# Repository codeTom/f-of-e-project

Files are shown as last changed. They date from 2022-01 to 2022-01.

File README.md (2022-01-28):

# Time of flight sensor based 3D mapper
## About
This project builds a slow 3D lidar alternative using 2 servos and a time of flight sensor.

## Firmware
The firmware is based on a stripped down version of [Warp-firmware](https://github.com/physical-computation/Warp-firmware), source can be found in src.
### Servo control
Servo driver can control 2 servos, see `src/boot/ksdk1.1.0/devServos.{h,c}` for more details. To allow higher resolution for PWM control, the default PWM driver was modified and now uses 1/1000 percent instead of percent for duty cycle unit.

### Distance sensor
A basic VL53L0X V2 driver is implemented in `src/boot/ksdk1.1.0/devVL53.{c,h}` based on [this post](https://www.artfulbytes.com/vl53l0x-post).

### Communication
The firmware sends data using the default warpPrint() function and it can be read using the standard JLink connection.

## Hardware
Models directory contains the 3D printed attachments (source in `servoholder.scad`) and the box svg file for 3mm material thickness. The openscad file requires some external stls for servos and the sensor which were obtained from grabcad.com. Servo arm scad file is from [this repo](https://github.com/hugokernel/OpenSCAD_ServoArms).

## Software and processing
`python/live.py` will display live data as they arrive and also output it to terminal for future processing. Make sure the JLink server is running and connected while using the script. As the live display in matplotlib is very slow, it's recommended to log output from live.py to a file and use `python/postprocess.py` to display it after a full scan was completed.

## How to reproduce this project
### Materials list
 * FRDM board
 * 2 9g Servos
 * VL53L0X V2 sensor
 * Some wires, optionally a breadboard
 * 3D printer
 * (optional) Laser cutter and 3mm material
 * 2 M3 screws
 * 4 M2 screws
 * 2 M2 nuts

### Process
1. Print `servoholder.stl` and `sensorholder.stl`.
2. Attach distance sensor to sensorholder
3. Screw servo to servoholder
4. Glue the larger servohorn to servoholder (elevation servo)
5. Connect the distance sensor to i2c on the FRDM
6. Load firmware to FRDM (`make warp && make warp-load`)
7. Attach small servo horn to the servo in the holder
8. Connect servo in the holder to 5V, ground and PTB11 (temporary)
9. Observe servo motion and adjust rotation of the arm so that it goes from horizontal to horizontal
10. Power off FRDM
11. Screw the sensor holder to the servo arm (securing the arm to the servo)
12. (optional) Cut and assemble the box, screw azimuth servo to the box and place FRDM in the box
13. Attach the servo holder to the azimuth servo so that the axes of the servo intersect (to reduce errors slightly)
14. Move elevation servo data cable to PTB10 (routing the cable sensibly)
15. Connect elevation servo to 5V, ground, and PTB11
16. Plug FRDM back in
17. Connect ot FRDM with JLink
18. Start `python/live.py > data.csv` and see the scan progress

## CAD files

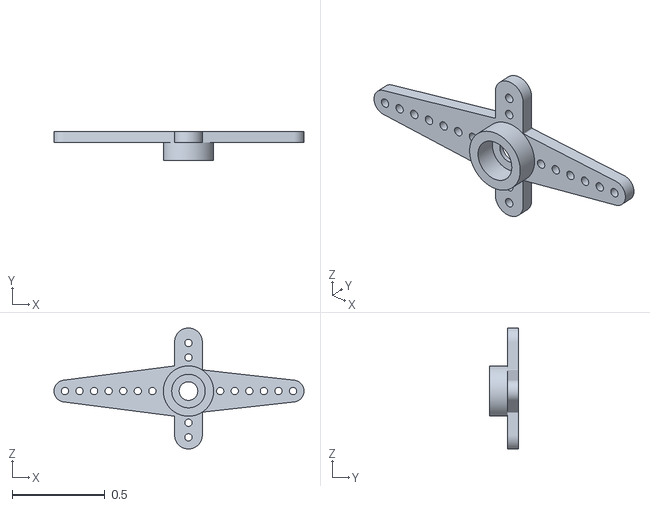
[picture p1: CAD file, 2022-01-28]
models/largearm.stl
1.35 x 0.157 x 0.654

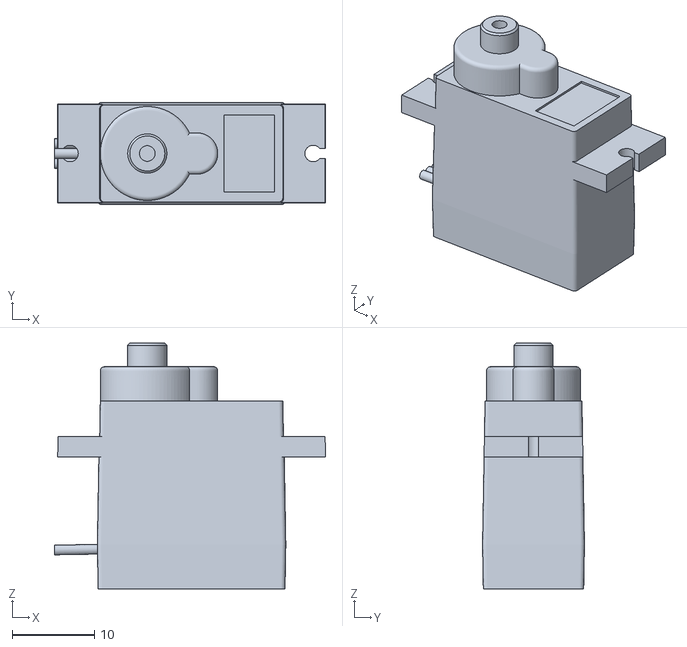
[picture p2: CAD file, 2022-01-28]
models/servo.stl
32.9 x 12.4 x 29.8

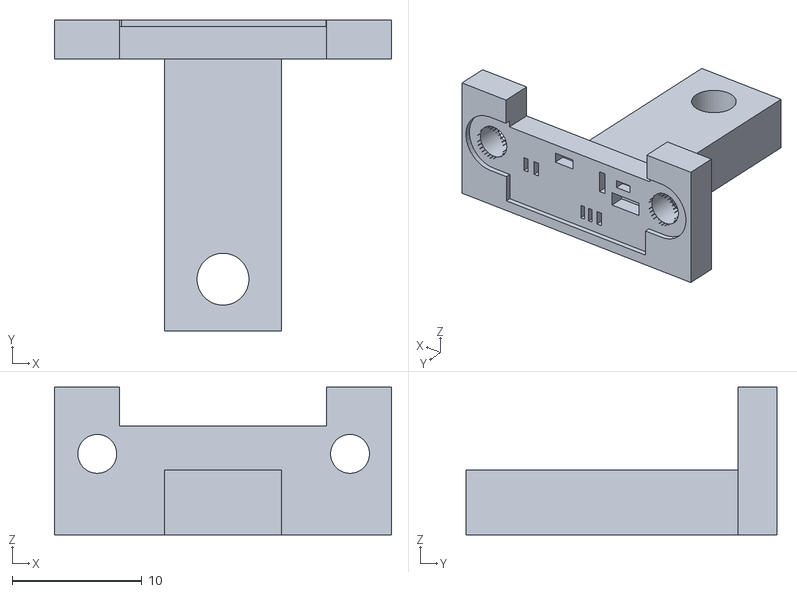
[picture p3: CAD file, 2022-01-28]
models/sensorholder.stl
26.0 x 24.0 x 11.4

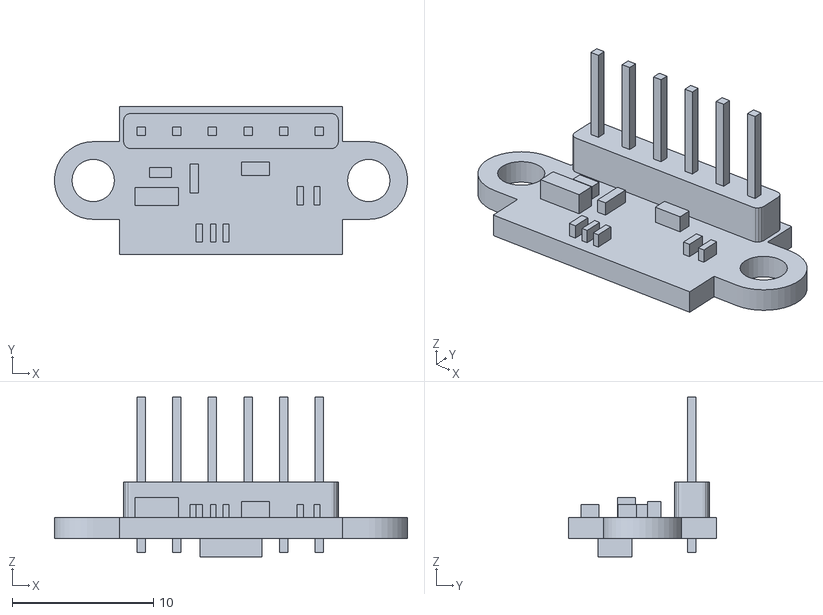
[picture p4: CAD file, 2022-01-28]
models/sensor.stl
25.0 x 10.5 x 11.3

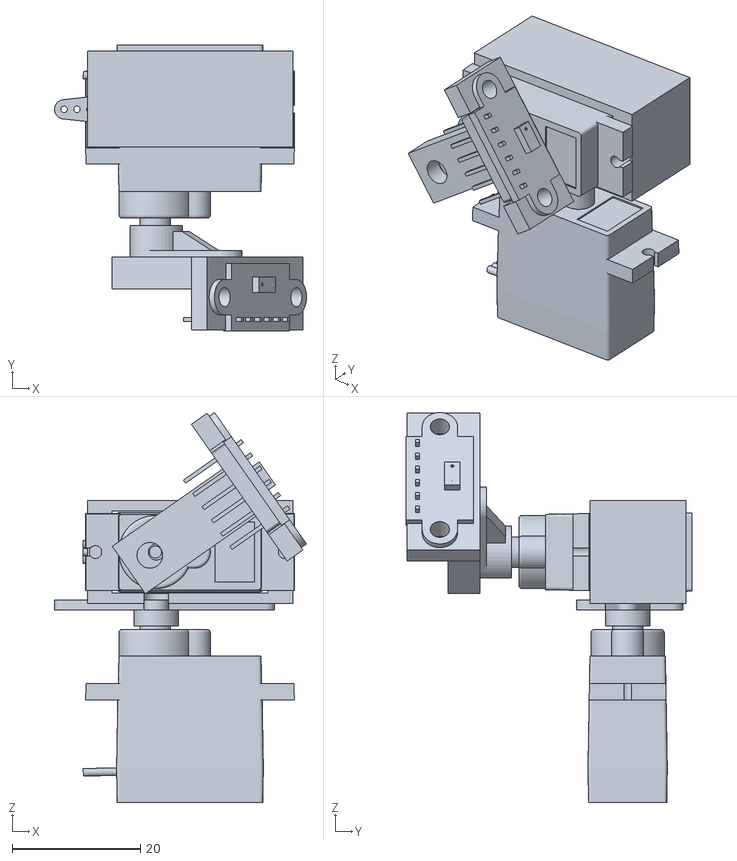
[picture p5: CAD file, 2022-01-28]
models/figure.stl
39.2 x 44.5 x 60.7

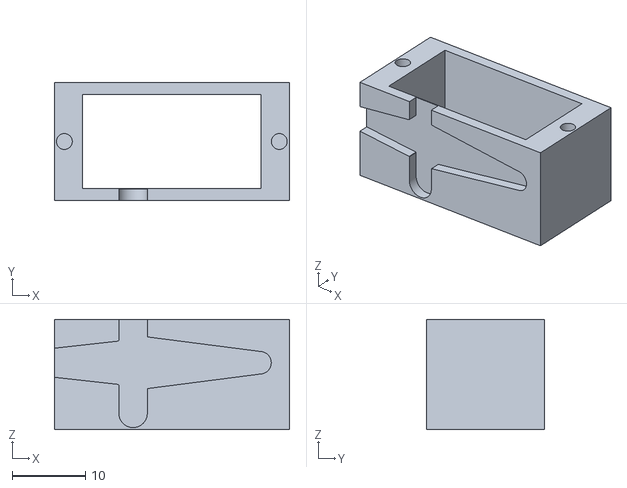
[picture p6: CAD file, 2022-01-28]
models/servoholder.stl
32.0 x 16.0 x 15.0

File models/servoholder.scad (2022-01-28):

use <MCAD/servos.scad>
use <servo_arm.scad>

$fn=50;

SERVO = [
    [5, 4, 1, 1.5],
    [25, 0.3, 0.7, 0.1]
];

module parts()
{
    hull()servo_arm(SERVO, [14,1]);
    translate([-19.7,21,-5])
    rotate([90,0,0])
        color("green")import("sensor.stl");
}

module screwholes()
{
    translate([0,0,2])cylinder(r=2,h=12,$fn=50);
    translate([-9.7,22,10.25])rotate([90,0,0]) cylinder(r=1.5, h=7, $fn=50);
    translate([9.8,22,10.25])rotate([90,0,0]) cylinder(r=1.5, h=7, $fn=50);
}

module core()
{
    plate_thickness = 3;
    translate([-4.5,-4,4])cube([9,24,5]);
    translate([-13,20-plate_thickness,4]) cube([26,plate_thickness,8.4]);
    translate([-13,20-plate_thickness,4+8.4]) cube([5,plate_thickness,3]);
    translate([8,20-plate_thickness,4+8.4]) cube([5,plate_thickness,3]);
}

/**
 * taken from https://github.com/openscad/MCAD/blob/master/servos.scad 
 *
 * @param vector position The position vector
 * @param vector rotation The rotation vector
 * @param boolean screws If defined then "screws" will be added and when the module is differenced() from something if will have holes for the screws
 * @param boolean cables If defined then "cables" output will be added and when the module is differenced() from something if will have holes for the cables output
 * @param number axle_length If defined this will draw a red indicator for the main axle
 */
module towerprosg90(position=undef, rotation=undef, screws = 0, axle_length = 0, cables=0)
{
	translate(position) rotate(rotation) {
        difference(){
            union()
            {
                translate([-5.9,-11.8/2,0]) cube([22.5,11.8,22.7]);
                translate([0,0,22.7-0.1]){
                    cylinder(d=11.8,h=4+0.1);
                    hull(){
                        translate([8.8-5/2,0,0]) cylinder(d=5,h=4+0.1);
                        cylinder(d=5,h=4+0.1);
                    }
                    translate([0,0,4]) cylinder(d=4.6,h=3.2);
                }
                translate([-4.7-5.9,-11.8/2,15.9]) cube([22.5+4.7*2, 11.8, 2.5]); 
            }
            //screw holes
            translate([-2.3-5.9,0,15.9+1.25]) cylinder(d=2,h=5, center=true);
            translate([-2.3-5.9-2,0,15.9+1.25]) cube([3,1.3,5], center=true);
            translate([2.3+22.5-5.9,0,15.9+1.25]) cylinder(d=2,h=5, center=true);
            translate([2.3+22.5-5.9+2,0,15.9+1.25]) cube([3,1.3,5], center=true);
        }
        if (axle_length > 0) {
            color("red", 0.3) translate([0,0,29.9/2]) cylinder(r=1, h=29.9+axle_length, center=true);
        }
        if (cables > 0) color("red", 0.3) translate([-12.4,-1.8,4.5]) cube([10,3.6,1.2]);
        if(screws > 0) color("red", 0.3) {
            translate([-2.3-5.9,0,15.9+1.25]) cylinder(d=2,h=10, center=true);
            translate([2.3+22.5-5.9,0,15.9+1.25]) cylinder(d=2,h=10, center=true);
        }
    }
    
}

module sensorholder()
{
    difference()
    {
        core();
        parts();
        screwholes();
    }
}


module largearm()
{
    intersection()
    {
        translate([-25,-0.1,-25])cube([50,50,50]);
        scale([25.4,25.4,25.4]) rotate([0,180,0])import("largearm.stl"); //stl from grabcad
    }

    translate([1.1,0.75,0])cube([33,1.5,2], center=true);
    translate([0,0.75,0]) cube([2,1.5,15], center=true);
    translate([0,0.75,0])rotate([90,0,0]) cylinder(h=1.5, r=2.8, center=true);
}

module servoholder()
{
    difference()
    {
        translate([-10.7,-8,0.9])cube([32,16,15]);
        translate([-0.5,0,0])scale([1.08,1.08,1])towerprosg90([0,0,0], [0,0,0], 1, 0, 0);
        translate([0,-8,10]) scale([1.02,1.02,1.02]) largearm();
    }
}

servoholder();

//towerprosg90([0,0,0], [0,0,0], 1, 0, 0);

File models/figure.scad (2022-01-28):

use <servoholder.scad>;
use <servo_arm.scad>

SERVO = [
    [5, 4, 1, 1.5],
    [25, 0.3, 0.7, 0.1]
];

module servo()
{
    translate([0,-51,0])color("lightblue") import("servo.stl");
}

module sensor()
{
    color("green")import("sensor.stl");
}
servo();
translate([10,10,23])rotate([90,0,0])
{
    color("white")translate([0,-9,10])scale([25.4,25.4,25.4]) rotate([0,180,0])import("largearm.stl");
    servoholder();
}
translate([0,-6,23]) rotate([90,0,0]) servo();
color("white")translate([10,-18,23])rotate([90,55,0])servo_standard(13, 1);
//translate([35,-10,0])rotate([-25,0,-90])rotate([0,90,0])sensor();

translate([9,-19,22.5])rotate([90,55,0]){
    sensorholder();
translate([-19.7,21,-5])
    rotate([90,0,0])
        color("green")import("sensor.stl");
}

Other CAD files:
models/servo_arm.scad

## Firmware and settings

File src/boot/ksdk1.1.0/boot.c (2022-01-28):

/*
	Authored 2016-2018. Phillip Stanley-Marbell.

	Additional contributions, 2018 onwards: See git blame.

	All rights reserved.

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
	*	Neither the name of the author nor the names of its
		contributors may be used to endorse or promote products
		derived from this software without specific prior written
		permission.

	THIS SOFTWARE IS PROVIDED BY THE COPYRIGHT HOLDERS AND CONTRIBUTORS
	"AS IS" AND ANY EXPRESS OR IMPLIED WARRANTIES, INCLUDING, BUT NOT
	LIMITED TO, THE IMPLIED WARRANTIES OF MERCHANTABILITY AND FITNESS
	FOR A PARTICULAR PURPOSE ARE DISCLAIMED. IN NO EVENT SHALL THE
	COPYRIGHT OWNER OR CONTRIBUTORS BE LIABLE FOR ANY DIRECT, INDIRECT,
	INCIDENTAL, SPECIAL, EXEMPLARY, OR CONSEQUENTIAL DAMAGES (INCLUDING,
	BUT NOT LIMITED TO, PROCUREMENT OF SUBSTITUTE GOODS OR SERVICES;
	LOSS OF USE, DATA, OR PROFITS; OR BUSINESS INTERRUPTION) HOWEVER
	CAUSED AND ON ANY THEORY OF LIABILITY, WHETHER IN CONTRACT, STRICT
	LIABILITY, OR TORT (INCLUDING NEGLIGENCE OR OTHERWISE) ARISING IN
	ANY WAY OUT OF THE USE OF THIS SOFTWARE, EVEN IF ADVISED OF THE
	POSSIBILITY OF SUCH DAMAGE.
*/
#include <stdio.h>
#include <stdlib.h>
#include <string.h>
#include <stdarg.h>

/*
 *	config.h needs to come first
 */
#include "config.h"

#include "fsl_misc_utilities.h"
#include "fsl_device_registers.h"
#include "fsl_i2c_master_driver.h"
#include "fsl_spi_master_driver.h"
#include "fsl_rtc_driver.h"
#include "fsl_clock_manager.h"
#include "fsl_power_manager.h"
#include "fsl_mcglite_hal.h"
#include "fsl_port_hal.h"
#include "fsl_lpuart_driver.h"
#include "warp.h"
#include "errstrs.h"
#include "gpio_pins.h"
#include "SEGGER_RTT.h"
#include "devINA219.h"
//#include "fsl_tpm_hal.h"
#include "fsl_tpm_driver.h"
#include "devServos.h"
#include "devVL53.h"

#define kWarpConstantStringI2cFailure "\rI2C failed, reg 0x%02x, code %d\n"
#define kWarpConstantStringErrorInvalidVoltage "\rInvalid supply voltage [%d] mV!"
#define kWarpConstantStringErrorSanity "\rSanity check failed!"

#if (WARP_BUILD_ENABLE_DEVSSD1331)
#include "devSSD1331.h"
//volatile WarpSPIDeviceState			deviceSSD1331State;
#endif

volatile i2c_master_state_t i2cMasterState;
volatile spi_master_state_t spiMasterState;
volatile spi_master_user_config_t spiUserConfig;
volatile lpuart_user_config_t lpuartUserConfig;
volatile lpuart_state_t lpuartState;

volatile bool gWarpBooted = false;
volatile uint32_t gWarpI2cBaudRateKbps = kWarpDefaultI2cBaudRateKbps;
volatile uint32_t gWarpUartBaudRateBps = kWarpDefaultUartBaudRateBps;
volatile uint32_t gWarpSpiBaudRateKbps = kWarpDefaultSpiBaudRateKbps;
volatile uint32_t gWarpSleeptimeSeconds = kWarpDefaultSleeptimeSeconds;
volatile WarpModeMask gWarpMode = kWarpModeDisableAdcOnSleep;
volatile uint32_t gWarpI2cTimeoutMilliseconds = kWarpDefaultI2cTimeoutMilliseconds;
volatile uint32_t gWarpSpiTimeoutMicroseconds = kWarpDefaultSpiTimeoutMicroseconds;
volatile uint32_t gWarpUartTimeoutMilliseconds = kWarpDefaultUartTimeoutMilliseconds;
volatile uint32_t gWarpMenuPrintDelayMilliseconds = kWarpDefaultMenuPrintDelayMilliseconds;
volatile uint32_t gWarpSupplySettlingDelayMilliseconds = kWarpDefaultSupplySettlingDelayMilliseconds;
volatile uint16_t gWarpCurrentSupplyVoltage = kWarpDefaultSupplyVoltageMillivolts;
char gWarpPrintBuffer[kWarpDefaultPrintBufferSizeBytes];

/*
 *	Since only one SPI transaction is ongoing at a time in our implementation
 */
uint8_t gWarpSpiCommonSourceBuffer[kWarpMemoryCommonSpiBufferBytes];
uint8_t gWarpSpiCommonSinkBuffer[kWarpMemoryCommonSpiBufferBytes];

static void lowPowerPinStates(void);
static int char2int(int character);

/*
 *	TODO: change the following to take byte arrays
 */
WarpStatus writeByteToI2cDeviceRegister(uint8_t i2cAddress, bool sendCommandByte, uint8_t commandByte, bool sendPayloadByte, uint8_t payloadByte);
WarpStatus writeBytesToSpi(uint8_t *payloadBytes, int payloadLength);

void warpLowPowerSecondsSleep(uint32_t sleepSeconds, bool forceAllPinsIntoLowPowerState);

/*
 *	Derived from KSDK power_manager_demo.c BEGIN>>>
 */
clock_manager_error_code_t clockManagerCallbackRoutine(clock_notify_struct_t *notify, void *callbackData);

/*
 *	static clock callback table.
 */
clock_manager_callback_user_config_t clockManagerCallbackUserlevelStructure =
	{
		.callback = clockManagerCallbackRoutine,
		.callbackType = kClockManagerCallbackBeforeAfter,
		.callbackData = NULL};

static clock_manager_callback_user_config_t *clockCallbackTable[] =
	{
		&clockManagerCallbackUserlevelStructure};

clock_manager_error_code_t
clockManagerCallbackRoutine(clock_notify_struct_t *notify, void *callbackData)
{
	clock_manager_error_code_t result = kClockManagerSuccess;

	switch (notify->notifyType)
	{
	case kClockManagerNotifyBefore:
		break;
	case kClockManagerNotifyRecover:
	case kClockManagerNotifyAfter:
		break;
	default:
		result = kClockManagerError;
		break;
	}

	return result;
}

/*
 *	Override the RTC IRQ handler
 */
void RTC_IRQHandler(void)
{
	if (RTC_DRV_IsAlarmPending(0))
	{
		RTC_DRV_SetAlarmIntCmd(0, false);
	}
}

/*
 *	Override the RTC Second IRQ handler
 */
void RTC_Seconds_IRQHandler(void)
{
	gWarpSleeptimeSeconds++;
}

/*
 *	LLW_IRQHandler override. Since FRDM_KL03Z48M is not defined,
 *	according to power_manager_demo.c, what we need is LLW_IRQHandler.
 *	However, elsewhere in the power_manager_demo.c, the code assumes
 *	FRDM_KL03Z48M _is_ defined (e.g., we need to use LLWU_IRQn, not
 *	LLW_IRQn). Looking through the code base, we see in
 *
 *		ksdk1.1.0/platform/startup/MKL03Z4/gcc/startup_MKL03Z4.S
 *
 *	that the startup initialization assembly requires LLWU_IRQHandler,
 *	not LLW_IRQHandler. See power_manager_demo.c, circa line 216, if
 *	you want to find out more about this dicsussion.
 */
void LLWU_IRQHandler(void)
{
	/*
	 *	BOARD_* defines are defined in warp.h
	 */
	LLWU_HAL_ClearExternalPinWakeupFlag(LLWU_BASE, (llwu_wakeup_pin_t)BOARD_SW_LLWU_EXT_PIN);
}

/*
 *	IRQ handler for the interrupt from RTC, which we wire up
 *	to PTA0/IRQ0/LLWU_P7 in Glaux. BOARD_SW_LLWU_IRQ_HANDLER
 *	is a synonym for PORTA_IRQHandler.
 */
void BOARD_SW_LLWU_IRQ_HANDLER(void)
{
	/*
	 *	BOARD_* defines are defined in warp.h
	 */
	PORT_HAL_ClearPortIntFlag(BOARD_SW_LLWU_BASE);
}

/*
 *	Power manager user callback
 */
power_manager_error_code_t
callback0(power_manager_notify_struct_t *notify, power_manager_callback_data_t *dataPtr)
{
	WarpPowerManagerCallbackStructure *callbackUserData = (WarpPowerManagerCallbackStructure *)dataPtr;
	power_manager_error_code_t status = kPowerManagerError;

	switch (notify->notifyType)
	{
	case kPowerManagerNotifyBefore:
		status = kPowerManagerSuccess;
		break;
	case kPowerManagerNotifyAfter:
		status = kPowerManagerSuccess;
		break;
	default:
		callbackUserData->errorCount++;
		break;
	}

	return status;
}
/*
 *	Derived from KSDK power_manager_demo.c <<END
 */

void sleepUntilReset(void)
{
	while (1)
	{
#if (WARP_BUILD_ENABLE_DEVSI4705)
		GPIO_DRV_SetPinOutput(kWarpPinSI4705_nRST);
#endif

		warpLowPowerSecondsSleep(1, false /* forceAllPinsIntoLowPowerState */);

#if (WARP_BUILD_ENABLE_DEVSI4705)
		GPIO_DRV_ClearPinOutput(kWarpPinSI4705_nRST);
#endif

		warpLowPowerSecondsSleep(60, true /* forceAllPinsIntoLowPowerState */);
	}
}

void enableLPUARTpins(void)
{
	/*
	 *	Enable UART CLOCK
	 */
	CLOCK_SYS_EnableLpuartClock(0);

	/*
	 *	Set UART pin association. See, e.g., page 99 in
	 *
	 *		https://www.nxp.com/docs/en/reference-manual/KL03P24M48SF0RM.pdf
	 *
	 *	Setup:
	 *		PTB3/kWarpPinI2C0_SCL_UART_TX for UART TX
	 *		PTB4/kWarpPinI2C0_SCL_UART_RX for UART RX

//TODO: we don't use hw flow control so don't need RTS/CTS
 *		PTA6/kWarpPinSPI_MISO_UART_RTS for UART RTS
 *		PTA7/kWarpPinSPI_MOSI_UART_CTS for UART CTS
	 */
	PORT_HAL_SetMuxMode(PORTB_BASE, 3, kPortMuxAlt3);
	PORT_HAL_SetMuxMode(PORTB_BASE, 4, kPortMuxAlt3);

	//TODO: we don't use hw flow control so don't need RTS/CTS
	//	PORT_HAL_SetMuxMode(PORTA_BASE, 6, kPortMuxAsGpio);
	//	PORT_HAL_SetMuxMode(PORTA_BASE, 7, kPortMuxAsGpio);
	//	GPIO_DRV_SetPinOutput(kWarpPinSPI_MISO_UART_RTS);
	//	GPIO_DRV_SetPinOutput(kWarpPinSPI_MOSI_UART_CTS);

	/*
	 *	Initialize LPUART0. See KSDK13APIRM.pdf section 40.4.3, page 1353
	 */
	lpuartUserConfig.baudRate = gWarpUartBaudRateBps;
	lpuartUserConfig.parityMode = kLpuartParityDisabled;
	lpuartUserConfig.stopBitCount = kLpuartOneStopBit;
	lpuartUserConfig.bitCountPerChar = kLpuart8BitsPerChar;
	lpuartUserConfig.clockSource = kClockLpuartSrcMcgIrClk;

	LPUART_DRV_Init(0, (lpuart_state_t *)&lpuartState, (lpuart_user_config_t *)&lpuartUserConfig);
}

void disableLPUARTpins(void)
{
	/*
	 *	LPUART deinit
	 */
	LPUART_DRV_Deinit(0);

	/*
	 *	Set UART pin association. See, e.g., page 99 in
	 *
	 *		https://www.nxp.com/docs/en/reference-manual/KL03P24M48SF0RM.pdf
	 *
	 *	Setup:
	 *		PTB3/kWarpPinI2C0_SCL_UART_TX for UART TX
	 *		PTB4/kWarpPinI2C0_SCL_UART_RX for UART RX

//TODO: we don't use the HW flow control and that messes with the SPI any way
 *		PTA6/kWarpPinSPI_MISO_UART_RTS for UART RTS
 *		PTA7/kWarpPinSPI_MOSI_UART_CTS for UART CTS
	 */
	PORT_HAL_SetMuxMode(PORTB_BASE, 3, kPortPinDisabled);
	PORT_HAL_SetMuxMode(PORTB_BASE, 4, kPortPinDisabled);

	//TODO: we don't use flow-control
	PORT_HAL_SetMuxMode(PORTA_BASE, 6, kPortMuxAsGpio);
	PORT_HAL_SetMuxMode(PORTA_BASE, 7, kPortMuxAsGpio);

	GPIO_DRV_ClearPinOutput(kWarpPinSPI_MISO_UART_RTS);
	GPIO_DRV_ClearPinOutput(kWarpPinSPI_MOSI_UART_CTS);

	/*
	 *	Disable LPUART CLOCK
	*/
	CLOCK_SYS_DisableLpuartClock(0);
}

WarpStatus
sendBytesToUART(uint8_t *bytes, size_t nbytes)
{
	lpuart_status_t status;

	status = LPUART_DRV_SendDataBlocking(0, bytes, nbytes, gWarpUartTimeoutMilliseconds);
	if (status != 0)
	{
		return kWarpStatusDeviceCommunicationFailed;
	}

	return kWarpStatusOK;
}

void warpEnableSPIpins(void)
{
	CLOCK_SYS_EnableSpiClock(0);

	/*	kWarpPinSPI_MISO_UART_RTS_UART_RTS --> PTA6 (ALT3)	*/
	PORT_HAL_SetMuxMode(PORTA_BASE, 6, kPortMuxAlt3);

	/*	kWarpPinSPI_MOSI_UART_CTS --> PTA7 (ALT3)	*/
	PORT_HAL_SetMuxMode(PORTA_BASE, 7, kPortMuxAlt3);

#if (WARP_BUILD_ENABLE_GLAUX_VARIANT)
	/*	kWarpPinSPI_SCK	--> PTA9	(ALT3)		*/
	PORT_HAL_SetMuxMode(PORTA_BASE, 9, kPortMuxAlt3);
#else
	/*	kWarpPinSPI_SCK	--> PTB0	(ALT3)		*/
	PORT_HAL_SetMuxMode(PORTB_BASE, 0, kPortMuxAlt3);
#endif

	/*
	 *	Initialize SPI master. See KSDK13APIRM.pdf Section 70.4
	 */
	uint32_t calculatedBaudRate;
	spiUserConfig.polarity = kSpiClockPolarity_ActiveHigh;
	spiUserConfig.phase = kSpiClockPhase_FirstEdge;
	spiUserConfig.direction = kSpiMsbFirst;
	spiUserConfig.bitsPerSec = gWarpSpiBaudRateKbps * 1000;
	SPI_DRV_MasterInit(0 /* SPI master instance */, (spi_master_state_t *)&spiMasterState);
	SPI_DRV_MasterConfigureBus(0 /* SPI master instance */, (spi_master_user_config_t *)&spiUserConfig, &calculatedBaudRate);
}

void warpDisableSPIpins(void)
{
	SPI_DRV_MasterDeinit(0);

	/*	kWarpPinSPI_MISO_UART_RTS	--> PTA6	(GPI)		*/
	PORT_HAL_SetMuxMode(PORTA_BASE, 6, kPortMuxAsGpio);

	/*	kWarpPinSPI_MOSI_UART_CTS	--> PTA7	(GPIO)		*/
	PORT_HAL_SetMuxMode(PORTA_BASE, 7, kPortMuxAsGpio);

#if (WARP_BUILD_ENABLE_GLAUX_VARIANT)
	/*	kWarpPinSPI_SCK	--> PTA9	(GPIO)			*/
	PORT_HAL_SetMuxMode(PORTA_BASE, 9, kPortMuxAsGpio);
#else
	/*	kWarpPinSPI_SCK	--> PTB0	(GPIO)			*/
	PORT_HAL_SetMuxMode(PORTB_BASE, 0, kPortMuxAsGpio);
#endif

	//TODO: we don't use HW flow control so can remove these since we don't use the RTS/CTS
	GPIO_DRV_ClearPinOutput(kWarpPinSPI_MOSI_UART_CTS);
	GPIO_DRV_ClearPinOutput(kWarpPinSPI_MISO_UART_RTS);
	GPIO_DRV_ClearPinOutput(kWarpPinSPI_SCK);

	CLOCK_SYS_DisableSpiClock(0);
}

void warpDeasserAllSPIchipSelects(void)
{
	/*
	 *	By default, assusme pins are currently disabled (e.g., by a recent lowPowerPinStates())
	 *
	 *	Drive all chip selects high to disable them. Individual drivers call this routine before
	 *	appropriately asserting their respective chip selects.
	 *
	 *	Setup:
	 *		PTA12/kWarpPinISL23415_SPI_nCS	for GPIO
	 *		PTA9/kWarpPinAT45DB_SPI_nCS	for GPIO
	 *		PTA8/kWarpPinADXL362_SPI_nCS	for GPIO
	 *		PTB1/kWarpPinFPGA_nCS		for GPIO
	 *
	 *		On Glaux
	 		PTB2/kGlauxPinFlash_SPI_nCS for GPIO
	 */
	PORT_HAL_SetMuxMode(PORTA_BASE, 12, kPortMuxAsGpio);
	PORT_HAL_SetMuxMode(PORTA_BASE, 9, kPortMuxAsGpio);
	PORT_HAL_SetMuxMode(PORTA_BASE, 8, kPortMuxAsGpio);
	PORT_HAL_SetMuxMode(PORTB_BASE, 1, kPortMuxAsGpio);
#if (WARP_BUILD_ENABLE_GLAUX_VARIANT)
	PORT_HAL_SetMuxMode(PORTB_BASE, 2, kPortMuxAsGpio);
#endif

#if (WARP_BUILD_ENABLE_DEVISL23415)
	GPIO_DRV_SetPinOutput(kWarpPinISL23415_SPI_nCS);
#endif

#if (WARP_BUILD_ENABLE_DEVAT45DB)
	GPIO_DRV_SetPinOutput(kWarpPinAT45DB_SPI_nCS);
#endif

#if (WARP_BUILD_ENABLE_DEVADXL362)
	GPIO_DRV_SetPinOutput(kWarpPinADXL362_SPI_nCS);
#endif

#if (WARP_BUILD_ENABLE_DEVICE40)
	GPIO_DRV_SetPinOutput(kWarpPinFPGA_nCS);
#endif

#if (WARP_BUILD_ENABLE_GLAUX_VARIANT)
	GPIO_DRV_SetPinOutput(kGlauxPinFlash_SPI_nCS);
#endif
}

void debugPrintSPIsinkBuffer(void)
{
	for (int i = 0; i < kWarpMemoryCommonSpiBufferBytes; i++)
	{
		warpPrint("\tgWarpSpiCommonSinkBuffer[%d] = [0x%02X]\n", i, gWarpSpiCommonSinkBuffer[i]);
	}
	warpPrint("\n");
}
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
int main(void)
{
	WarpStatus status;
	uint8_t key;
	volatile WarpI2CDeviceState *menuI2cDevice = NULL;
	uint8_t menuRegisterAddress = 0x00;
	rtc_datetime_t warpBootDate;
	power_manager_user_config_t warpPowerModeWaitConfig;
	power_manager_user_config_t warpPowerModeStopConfig;
	power_manager_user_config_t warpPowerModeVlpwConfig;
	power_manager_user_config_t warpPowerModeVlpsConfig;
	power_manager_user_config_t warpPowerModeVlls0Config;
	power_manager_user_config_t warpPowerModeVlls1Config;
	power_manager_user_config_t warpPowerModeVlls3Config;
	power_manager_user_config_t warpPowerModeRunConfig;

	/*
	 *	We use this as a template later below and change the .mode fields for the different other modes.
	 */
	const power_manager_user_config_t warpPowerModeVlprConfig = {
		.mode = kPowerManagerVlpr,
		.sleepOnExitValue = false,
		.sleepOnExitOption = false};

	power_manager_user_config_t const *powerConfigs[] = {
		/*
							 *	NOTE: POWER_SYS_SetMode() depends on this order
							 *
							 *	See KSDK13APIRM.pdf Section 55.5.3
							 */
		&warpPowerModeWaitConfig,
		&warpPowerModeStopConfig,
		&warpPowerModeVlprConfig,
		&warpPowerModeVlpwConfig,
		&warpPowerModeVlpsConfig,
		&warpPowerModeVlls0Config,
		&warpPowerModeVlls1Config,
		&warpPowerModeVlls3Config,
		&warpPowerModeRunConfig,
	};

	WarpPowerManagerCallbackStructure powerManagerCallbackStructure;

	/*
	 *	Callback configuration structure for power manager
	 */
	const power_manager_callback_user_config_t callbackCfg0 = {
		callback0,
		kPowerManagerCallbackBeforeAfter,
		(power_manager_callback_data_t *)&powerManagerCallbackStructure};

	/*
	 *	Pointers to power manager callbacks.
	 */
	power_manager_callback_user_config_t const *callbacks[] = {
		&callbackCfg0};

	/*
	 *	Enable clock for I/O PORT A and PORT B
	 */
	CLOCK_SYS_EnablePortClock(0);
	CLOCK_SYS_EnablePortClock(1);

	/*
	 *	Set board crystal value (Warp revB and earlier).
	 */
	g_xtal0ClkFreq = 32768U;

	/*
	 *	Initialize KSDK Operating System Abstraction layer (OSA) layer.
	 */
	OSA_Init();

	/*
	 *	Setup SEGGER RTT to output as much as fits in buffers.
	 *
	 *	Using SEGGER_RTT_MODE_BLOCK_IF_FIFO_FULL can lead to deadlock, since
	 *	we might have SWD disabled at time of blockage.
	 */
	SEGGER_RTT_ConfigUpBuffer(0, NULL, NULL, 0, SEGGER_RTT_MODE_NO_BLOCK_TRIM);

	/*
	 *	Configure Clock Manager to default, and set callback for Clock Manager mode transition.
	 *
	 *	See "Clocks and Low Power modes with KSDK and Processor Expert" document (Low_Power_KSDK_PEx.pdf)
	 */
	CLOCK_SYS_Init(g_defaultClockConfigurations,
				   CLOCK_CONFIG_NUM, /* The default value of this is defined in fsl_clock_MKL03Z4.h as 2 */
				   &clockCallbackTable,
				   ARRAY_SIZE(clockCallbackTable));
	CLOCK_SYS_UpdateConfiguration(CLOCK_CONFIG_INDEX_FOR_RUN, kClockManagerPolicyForcible);

	/*
	 *	Initialize RTC Driver (not needed on Glaux, but we enable it anyway for now
	 *	as that lets us use the current sleep routines). NOTE: We also don't seem to
	 *	be able to go to VLPR mode unless we enable the RTC.
	 */
	RTC_DRV_Init(0);

	/*
	 *	Set initial date to 1st January 2016 00:00, and set date via RTC driver
	 */
	warpBootDate.year = 2016U;
	warpBootDate.month = 1U;
	warpBootDate.day = 1U;
	warpBootDate.hour = 0U;
	warpBootDate.minute = 0U;
	warpBootDate.second = 0U;
	RTC_DRV_SetDatetime(0, &warpBootDate);

	/*
	 *	Setup Power Manager Driver
	 */
	memset(&powerManagerCallbackStructure, 0, sizeof(WarpPowerManagerCallbackStructure));

	warpPowerModeVlpwConfig = warpPowerModeVlprConfig;
	warpPowerModeVlpwConfig.mode = kPowerManagerVlpw;

	warpPowerModeVlpsConfig = warpPowerModeVlprConfig;
	warpPowerModeVlpsConfig.mode = kPowerManagerVlps;

	warpPowerModeWaitConfig = warpPowerModeVlprConfig;
	warpPowerModeWaitConfig.mode = kPowerManagerWait;

	warpPowerModeStopConfig = warpPowerModeVlprConfig;
	warpPowerModeStopConfig.mode = kPowerManagerStop;

	warpPowerModeVlls0Config = warpPowerModeVlprConfig;
	warpPowerModeVlls0Config.mode = kPowerManagerVlls0;

	warpPowerModeVlls1Config = warpPowerModeVlprConfig;
	warpPowerModeVlls1Config.mode = kPowerManagerVlls1;

	warpPowerModeVlls3Config = warpPowerModeVlprConfig;
	warpPowerModeVlls3Config.mode = kPowerManagerVlls3;

	warpPowerModeRunConfig.mode = kPowerManagerRun;

	POWER_SYS_Init(&powerConfigs,
				   sizeof(powerConfigs) / sizeof(power_manager_user_config_t *),
				   &callbacks,
				   sizeof(callbacks) / sizeof(power_manager_callback_user_config_t *));

	/*
	 *	Initialize the GPIO pins with the appropriate pull-up, etc.,
	 *	defined in the inputPins and outputPins arrays (gpio_pins.c).
	 *
	 *	See also Section 30.3.3 GPIO Initialization of KSDK13APIRM.pdf
	 */
	warpPrint("About to GPIO_DRV_Init()... ");
	GPIO_DRV_Init(inputPins /* input pins */, outputPins /* output pins */);
	warpPrint("done.\n");

	/*
	 *	Make sure the SWD pins, PTA0/1/2 SWD pins in their ALT3 state (i.e., as SWD).
	 *
	 *	See GitHub issue https://github.com/physical-computation/Warp-firmware/issues/54
	 */
	PORT_HAL_SetMuxMode(PORTA_BASE, 0, kPortMuxAlt3);
	PORT_HAL_SetMuxMode(PORTA_BASE, 1, kPortMuxAlt3);
	PORT_HAL_SetMuxMode(PORTA_BASE, 2, kPortMuxAlt3);

	/*
	 *	Note that it is lowPowerPinStates() that sets the pin mux mode,
	 *	so until we call it pins are in their default state.
	 */
	lowPowerPinStates();

	/*
	 *	At this point, we consider the system "booted" and, e.g., warpPrint()s
	 *	will also be sent to the BLE if that is compiled in.
	 */
	gWarpBooted = true;
	warpPrint("Boot done.\n");

	devSSD1331init();
	//
	//	tpm_pwm_param_t pwm_param =
	//	{
	//		.mode = kTpmCenterAlignedPWM,         /*!< TPM PWM operation mode */
	//		.edgeMode = kTpmHighTrue,    /*!< PWM output mode */
	//		.uFrequencyHZ = 500u,           /*!< PWM period in Hz */
	//		.uDutyCyclePercent = 60u //this has been modified to represent 0.1 percent for better resolution
	//	};
	//
	//	//TODO: choose mode?
	//	//PTB10, alt2 => TPM0_CH1
	//	//PTA6, alt2 => TPM0_CH0
	//	//PTA5, alt2 => TPM0_CH1
	//	//PTB11, alt2 => TPM0_CH0
	//
	//	//THIS WORKS!!!!!!!!!!!!!!!!!!!!!!!!!!!!!
	//	PORT_HAL_SetMuxMode(PORTB_BASE, 10, kPortMuxAlt2);
	//
	//	tpm_general_config_t driverInfo;
	//	memset(&driverInfo, 0, sizeof(driverInfo));
	//	TPM_DRV_Init(0, &driverInfo);
	//
	//	warpPrint("Setting clock mode");
	//	TPM_DRV_SetClock(0, kTpmClockSourceModuleClk, kTpmDividedBy16);
	//	uint8_t pwm_start = TPM_DRV_PwmStart(0, &pwm_param, 1) ? 0 : 1; //TPM0_CH1
	//	//uint8_t pwm_start = TPM_DRV_PwmStart(0, &pwm_param, 0); //TPM0_CH1
	//	warpPrint("Started PWM output: %d, %d Hz, %d", pwm_start, TPM_DRV_GetClock(0), TPM_HAL_GetClockMode(g_tpmBaseAddr[0]));
	//	//TODO: init servos
	//	//TODO: init i2c distance sensor
	//	//want 1-2ms pulses
	//	//500Hz => 50% = 2ms => 50-99 (resolution is shit)

	initServos();
	uint8_t angle = 0;
	/*
	moveServo(1, angle);
	warpPrint("moving to %d\n", angle);
	OSA_TimeDelay(3000);
	angle=90;

	moveServo(1, angle);
	warpPrint("moving to %d\n", angle);
	OSA_TimeDelay(3000);
	angle=180;

	moveServo(1, angle);
	warpPrint("moving to %d\n", angle);
	OSA_TimeDelay(3000);
*/
	bool success = vl53_init();
	if (!success)
	{
		warpPrint("Failed to initialise VL53!\n");
		return -1;
	}

	int16_t min_elevation = 0;
	int16_t azimuth = 0; //handle overflows gracefully
	int16_t elevation = min_elevation;
	int8_t azimuth_step = 2;
	int8_t elevation_step = 2;
	//quarter sphere snake scan mode:
	//scan 180 deg of azimuth, increase elevation by 1
	moveServo(1, elevation);

	warpPrint("azimuth/deg,elevation/deg,range/mm\n");

	while (1)
	{
		uint16_t range = vl53_read();
		//if (range <= VL53L0X_OUT_OF_RANGE)
		warpPrint("%d,%d,%d\n", azimuth, elevation, range);

		//if we reached max azimuth, step elevation
		if ((azimuth >= 180 && azimuth_step > 0) || (azimuth <= 0 && azimuth_step < 0))
		{
			if ((elevation >= 180 && elevation_step > 0) || (elevation <= min_elevation && elevation_step < 0))
				elevation_step *= -1; //scan done, go backwards

			elevation += elevation_step;
			//cap to handle different step sizes
			if (elevation < 0)
				elevation = min_elevation;
			if (elevation > 180)
				elevation = 180;

			azimuth_step *= -1;
		}

		azimuth += azimuth_step;

		if (azimuth < 0)
			azimuth = 0;
		if (azimuth > 180)
			azimuth = 180; //warpPrint("moving to %d\n", angle);

		moveServo(1, elevation);
		moveServo(0, azimuth);
		OSA_TimeDelay(abs(azimuth_step) * 3);
	}

	return 0;
}

int char2int(int character)
{
	if (character >= '0' && character <= '9')
	{
		return character - '0';
	}

	if (character >= 'a' && character <= 'f')
	{
		return character - 'a' + 10;
	}

	if (character >= 'A' && character <= 'F')
	{
		return character - 'A' + 10;
	}

	return 0;
}
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

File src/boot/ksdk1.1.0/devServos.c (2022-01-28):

#include <stdint.h>

/*
 *	config.h needs to come first
 */
#include "config.h"
#include "devServos.h"

#include "fsl_port_hal.h"
#include "fsl_tpm_driver.h"

//running at higher frequency than the default 50Hz seems to reduce jitter and random jumps
#define SERVO_FREQUENCY_SCALING 5 //this seems to be max reliable value

tpm_pwm_param_t pwm_params[2];

uint8_t initServos()
{
	for (int i=0; i<2; i++)
	{
		pwm_params[i].mode = kTpmEdgeAlignedPWM;         /*!< TPM PWM operation mode */
		pwm_params[i].edgeMode = kTpmHighTrue;    /*!< PWM output mode */
		pwm_params[i].uFrequencyHZ = 50u * SERVO_FREQUENCY_SCALING;           /*!< PWM period in Hz */
		pwm_params[i].uDutyCyclePercent = 0u; //this has been modified to be 1/1000 of a percent instead
	}

	//TODO: choose mode?
	//PTB10, alt2 => TPM0_CH1
	//PTA6, alt2 => TPM0_CH0
	//PTA5, alt2 => TPM0_CH1
	//PTB11, alt2 => TPM0_CH0

	//THIS WORKS!!!!!!!!!!!!!!!!!!!!!!!!!!!!!
	
	PORT_HAL_SetMuxMode(PORTB_BASE, 11, kPortMuxAlt2); //servo 0 = ptb11
	PORT_HAL_SetMuxMode(PORTB_BASE, 10, kPortMuxAlt2); //servo 1 = ptb10
	
	
	tpm_general_config_t driverInfo;
	memset(&driverInfo, 0, sizeof(driverInfo));
	TPM_DRV_Init(0, &driverInfo);
	
	//warpPrint("Setting clock mode");
	TPM_DRV_SetClock(0, kTpmClockSourceModuleClk, kTpmDividedBy32);
	
	return 0;
}

uint8_t moveServo(uint8_t servo, uint8_t angle)
{
	//datasheet: 50Hz, 1-2ms
	//50Hz = 20ms PWM period, 180 points in 1ms => 3600 pwm resolution
	//uint32_t max value = 
	//convert angle to PWM setting
	//we are running at 50Hz = 20ms => 10%=10000 gives a 2ms pulse = 180, 5% = 5000 gives a 1ms pulse = 0
	//arduino testing shows 0.5ms -> 2.5ms yields 180degrees
	//this should be calibrated per servo to get the exact start and end positions
	//0.5ms -> 2.5ms gives 2500 - 12500
	//these values give 180 degrees of range
	uint16_t minpulse = 2800*SERVO_FREQUENCY_SCALING; //2500
	uint16_t maxpulse = 11800*SERVO_FREQUENCY_SCALING; //12500

	if (angle > 180)
		return 1;

	//pwm_params[servo].uDutyCyclePercent = (uint32_t) 5000 + 5000ul*angle/180;
	pwm_params[servo].uDutyCyclePercent = (uint32_t) minpulse + (maxpulse-minpulse)*angle/180;
	//warpPrint("Setting servo %d to %d duty cycle", servo, pwm_params[servo].uDutyCyclePercent);

	return TPM_DRV_PwmStart(0, &pwm_params[servo], servo) ? 0 : 1;
}

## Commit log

2022-01-28 Project models and processing scripts
    [figure.scad, figure.stl, largearm.stl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]
2022-01-28 add readme, servo_arm.scad
    [servo_arm.scad]
